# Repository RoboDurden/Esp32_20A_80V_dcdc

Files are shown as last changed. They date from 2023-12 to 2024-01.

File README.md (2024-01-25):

# Esp32_20A_80V_dcdc
 20A 80V dcdc/mppt with Esp32 and touch display

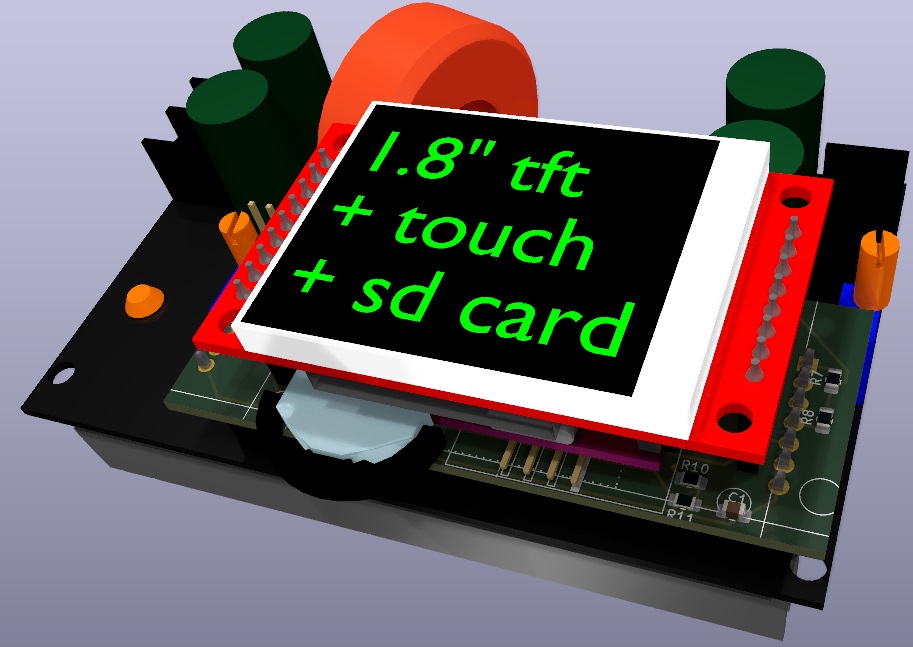
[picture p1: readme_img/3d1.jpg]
3d1


## KiCad pcb
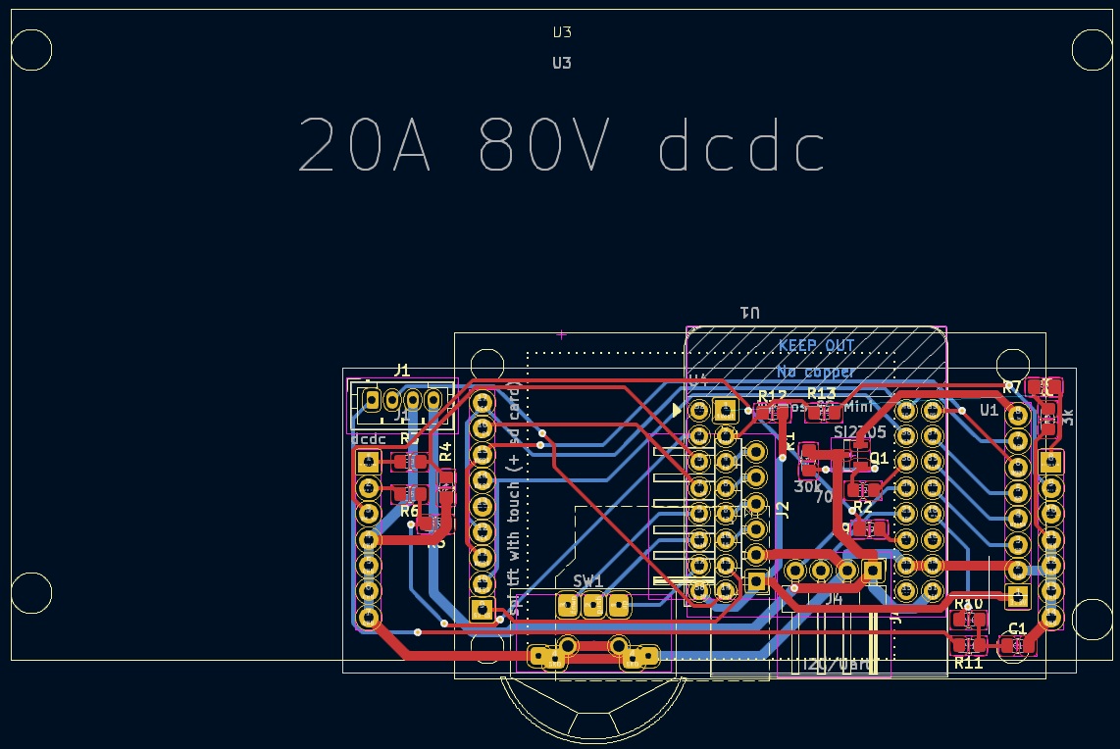
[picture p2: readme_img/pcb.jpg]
pcb


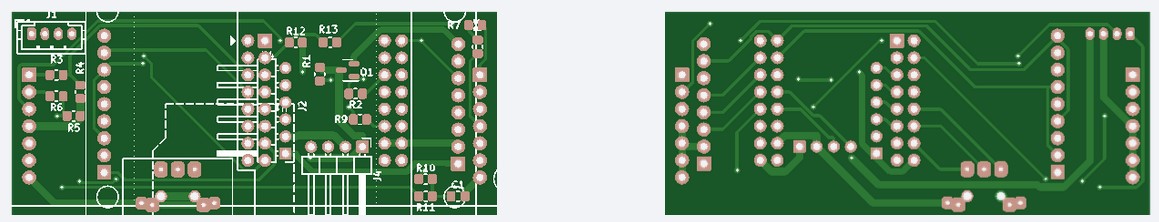
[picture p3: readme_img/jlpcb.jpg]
jlpcb


## replaces lcd pickup module
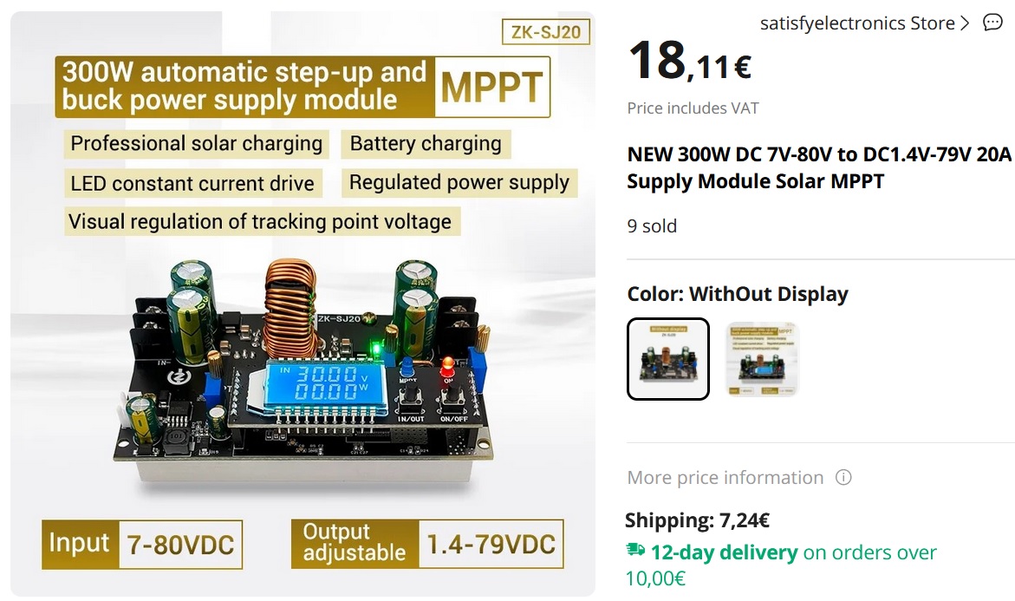
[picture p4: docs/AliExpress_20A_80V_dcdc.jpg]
AliExpress_20A_80V_dcdc

https://www.aliexpress.com/item/1005004966830126.html

## KiCad circuit
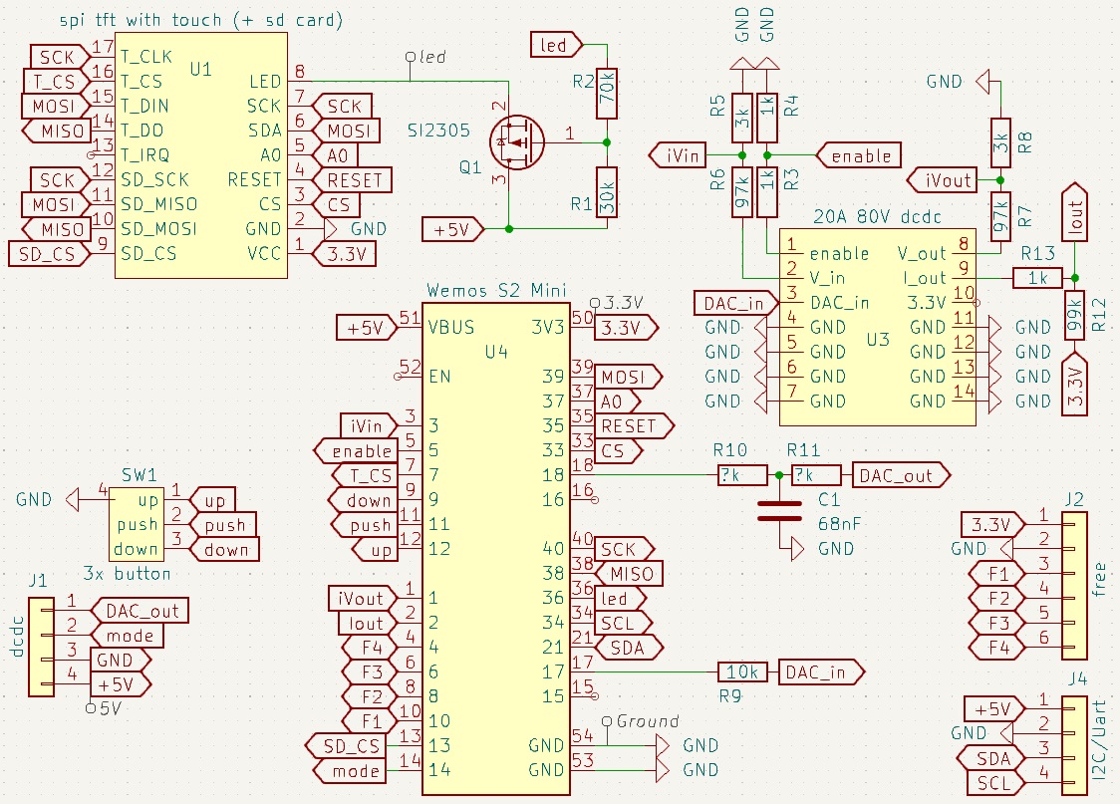
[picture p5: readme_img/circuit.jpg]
circuit


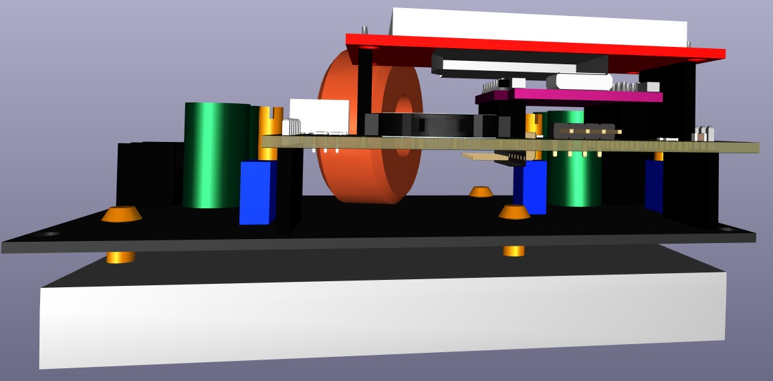
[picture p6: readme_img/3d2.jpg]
3d2

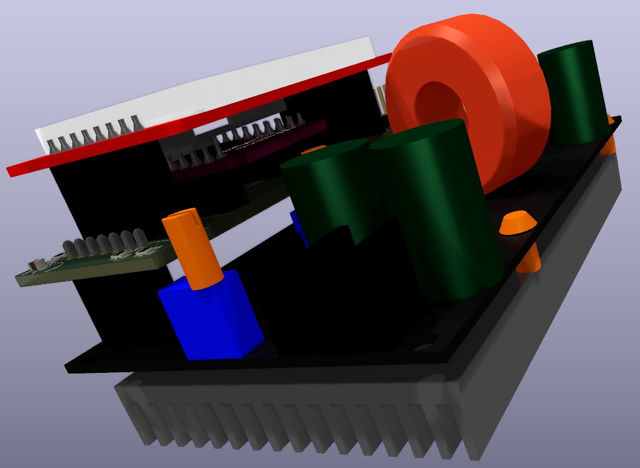
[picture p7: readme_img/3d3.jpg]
3d3


## blender 3d models
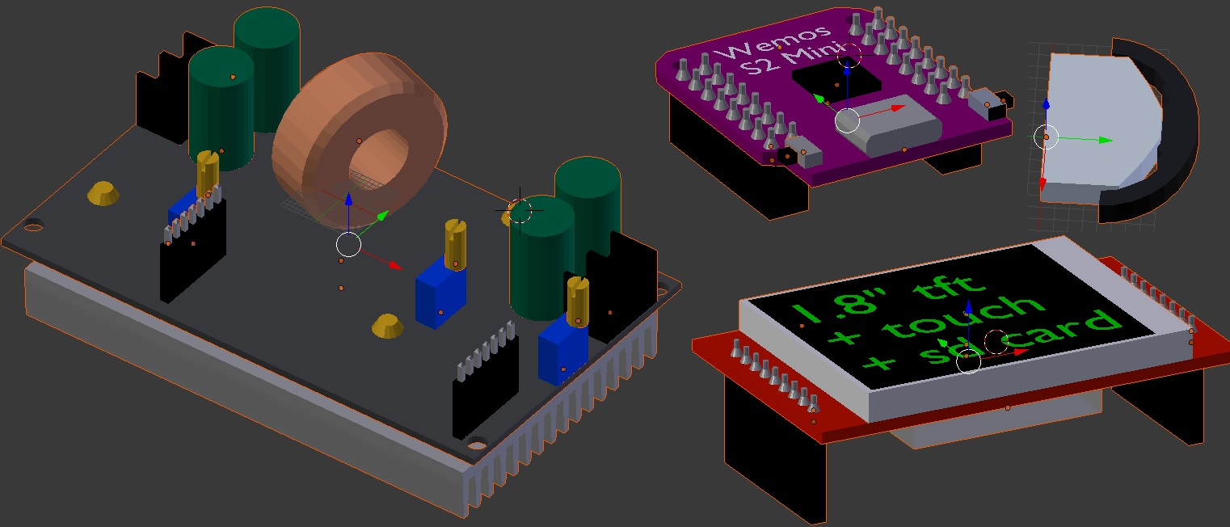
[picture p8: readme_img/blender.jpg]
blender


## blender box / housing
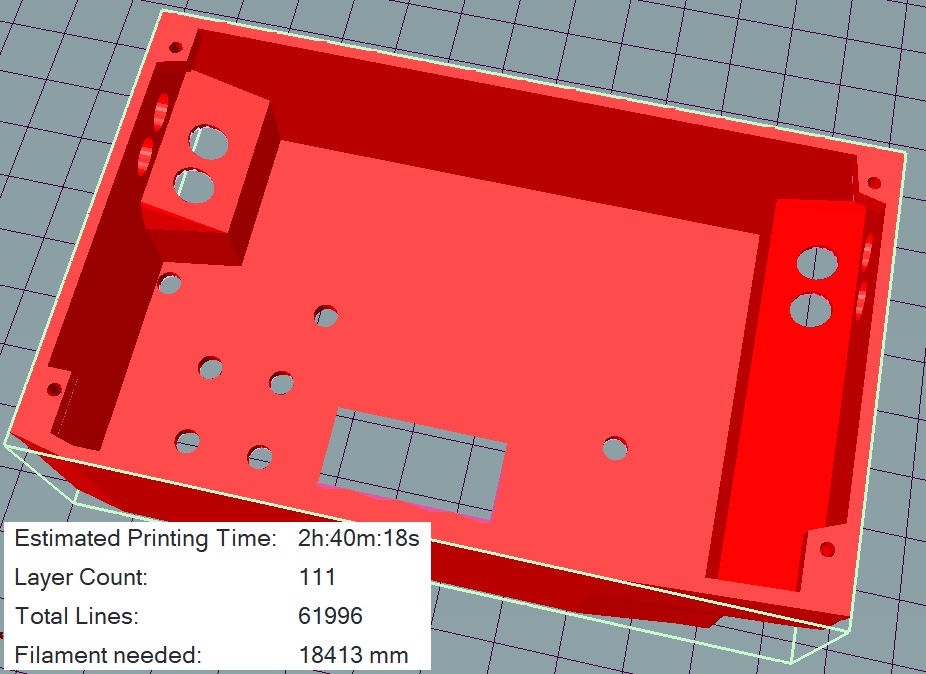
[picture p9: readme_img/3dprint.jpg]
3dprint


## Arduino code (ssd1306)
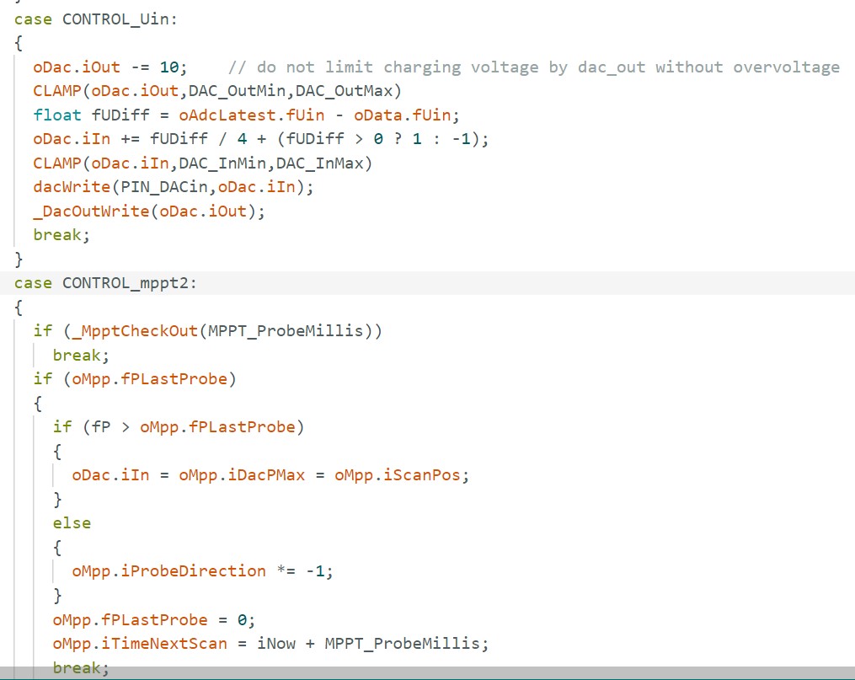
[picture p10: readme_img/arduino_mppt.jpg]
arduino_mppt


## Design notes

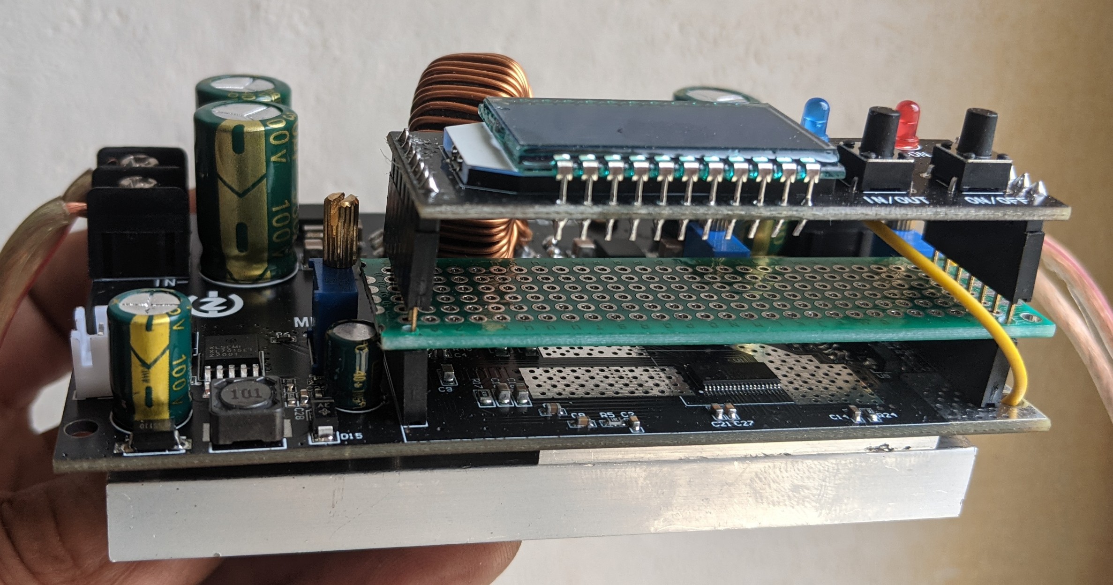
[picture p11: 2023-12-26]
docs/20A zwischenplatine.jpg

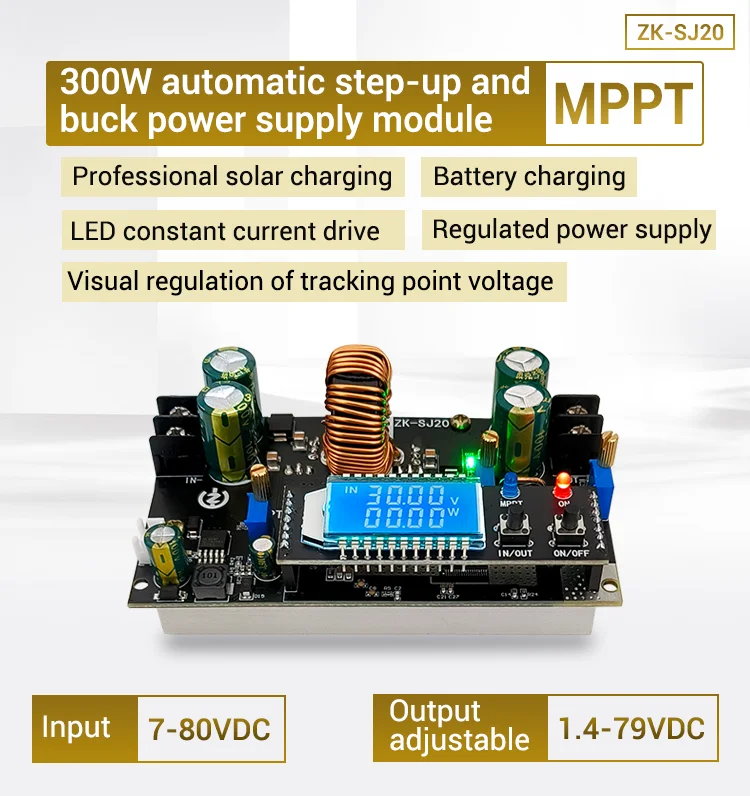
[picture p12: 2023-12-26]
docs/AliExpress dcdc/S2a203e523679416e9ab4497371176a7bX.webp

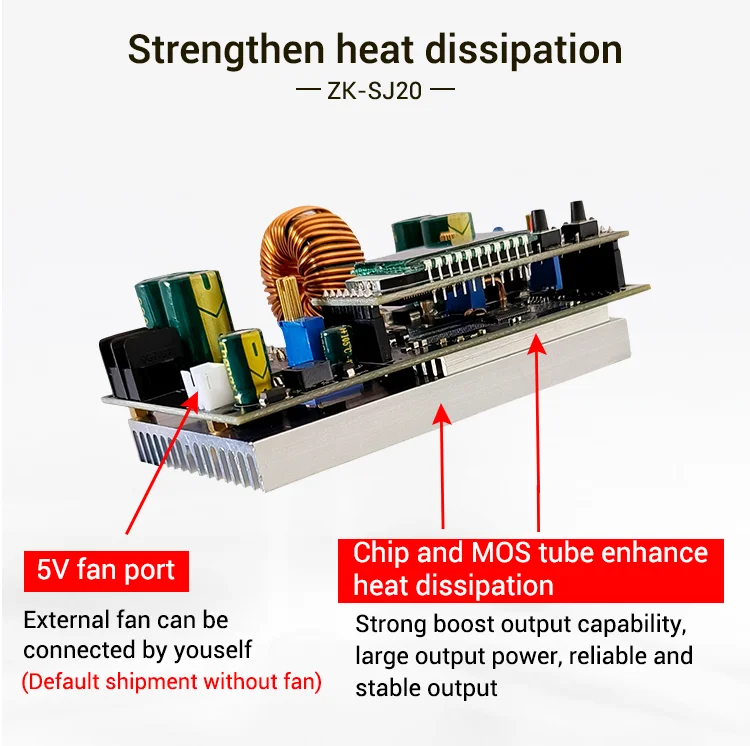
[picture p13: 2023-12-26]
docs/AliExpress dcdc/S84ae75041aaa493dba6d3abf79ab302bl.webp

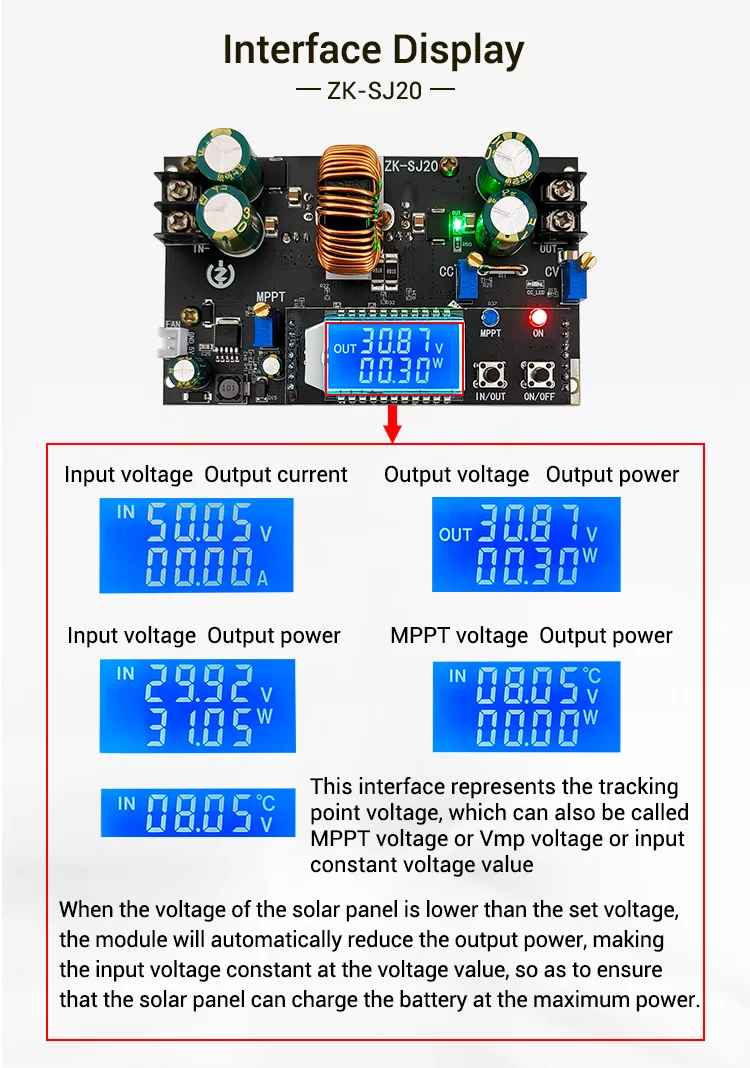
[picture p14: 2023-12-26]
docs/AliExpress dcdc/S4756472754be430b8e450a2648e028b7n.webp

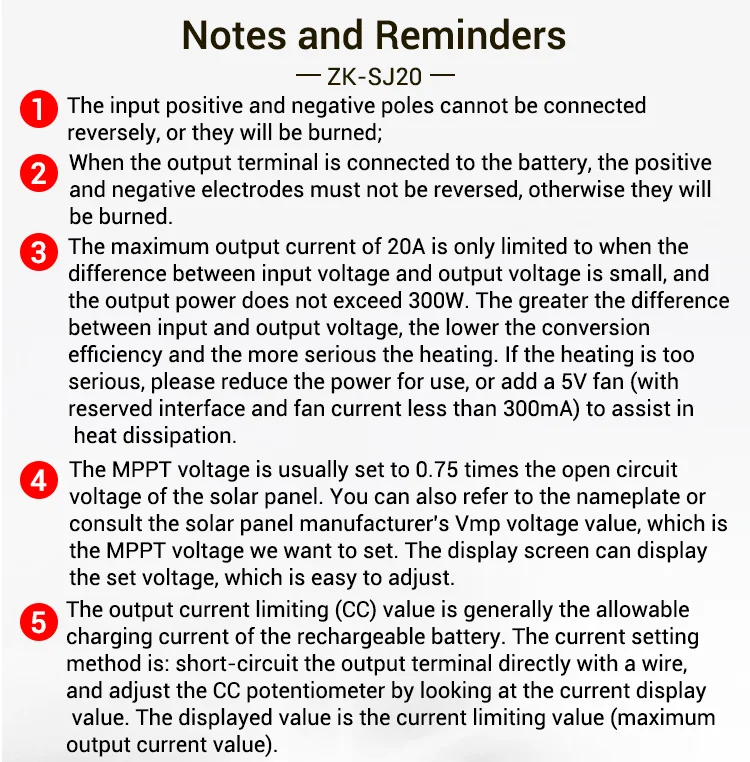
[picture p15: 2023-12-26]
docs/AliExpress dcdc/S0f6dcd9602464cfba2c723f9ad181f63F.webp

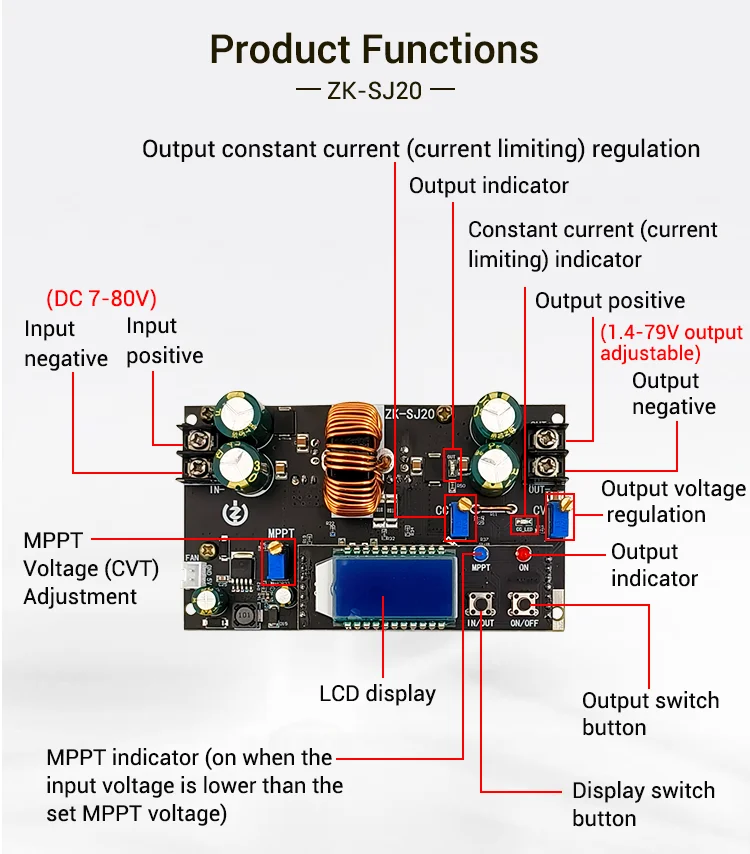
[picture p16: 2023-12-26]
docs/AliExpress dcdc/Sabfc8f4361d64af885e887af762c08adi.webp

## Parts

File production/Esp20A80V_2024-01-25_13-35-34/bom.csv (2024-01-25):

Designator | Footprint | Quantity | Value | LCSC Part #
C1 | 0805 | 1 | 68nF
J1 | JST_PH_B4B-PH-K_1x04_P2.00mm_Vertical | 1 | dcdc
J2 | PinHeader_1x06_P2.54mm_Horizontal | 1 | free
J4 | PinHeader_1x04_P2.54mm_Horizontal | 1 | I2C/Uart
Q1 | SOT-23 | 1 | SI2305
R1 | 0805 | 1 | 30k
R10, R11 | 0805 | 2 | ?k
R12 | 0805 | 1 | 99k
R13, R3, R4 | 0805 | 3 | 1k
R2 | 0805 | 1 | 70k
R5, R8 | 0805 | 2 | 3k
R6, R7 | 0805 | 2 | 97k
R9 | 0805 | 1 | 10k
SW1 | 3way dial switch | 1 | 3x button
U1 | display 128x160 +touch +sd | 1 | spi tft with touch (+ sd card)
U3 | 20A80V dcdc | 1 | 20A 80V dcdc
U4 | Wemos S2 Mini | 1 | Wemos S2 Mini

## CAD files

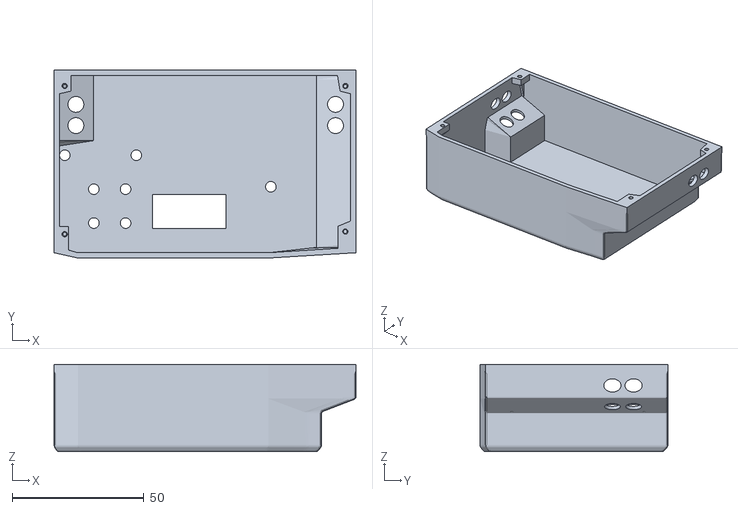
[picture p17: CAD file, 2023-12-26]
Blender housing/box 20A mppt no Esp32.stl
114.8 x 71.5 x 33.2

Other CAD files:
Blender housing/box 20A mppt 2.blend
Blender/Esp20A80V.blend

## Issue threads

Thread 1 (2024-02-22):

questions about the power supply module

AILIFE4798, 2024-02-22:
hi, i want to make a portable variable power supply controlled by esp32
i want to ask some question about the module
1. is the module synchronus aka there is 4 mosfet operating the inductor in full bridge
it can highly increase effiency and reduce heat
2. the original module have potentiometer for adjustment insted of button, that in most case mean it is not truely digitaly controlled, but i need my project to only use a single touch screen without any analog component, can the esp32 control the voltage and constant current
3. in these cheap module, the constant current is done in software, there is a pid loop to control the voltage based on the current feedback, so the software have to be very fast to react, i want to know if you set voltage to for example 30v and constant current 0.01a and connect a single led to it, will the supply react fast enough to not blow up the led

RoboDurden, 2024-02-23:
Long answer later.
Yes 4 mosfet.
My PCB is not tested yet.
My PCB only features 8 bit resolution for v_in and v_out. Potentiometers set the offset voltage, a resistor on PCB the range +- x Volt. So 2x/255 is the resolution.
Current control only via PID of voltage. Only good enough for charging or mppt .
Can not pull voltage down from 30V to 0.6V.
With external 4x 12bit DAC chip from MCP , direct digital current control should be possible.
There is a guy in Cina who designed a ltc8705 dcdc with four potentiometers. But I was not able to get in contact with him ...

RoboDurden, 2024-02-23:
http://m.eeworld.com.cn/RDesigns_detail/56242

AILIFE4798, 2024-02-23:
4 mosfet then this is the best module online ive seen so far
i have some 36v 4a ones with fp5139 pwm chip and same nuvoton microcontroller they are fully digital using encoder and button
i am willing to use external dac, but dac is not necessary in this case, using pwm and opamp is better(use pwm and rc filter, the opamp will have infinate input resistant and 0 output resistant to keep result stable)
esp32 have hardware pwm so it should be good
constant current via pid loop of voltage can be used as normal bench supply, dps5005 does that, and i know some other clones also do, just the software need to be fast and optimized
so with external dac can i control 0.6 to 50v at least 80v would be good to have
the guy that made his own module is not using digital control so its not really useful

AILIFE4798, 2024-02-23:
there is no such thing as digital pwm ic
they already are, just using a comparator as input voltage feedback and you have to offset it somehow
i will reverse engineer the 36v one that have 2 lm317 opamp
see how they designed it

idk what the input voltage adjust is used for
only out voltage this one is needed
i dont need hardware output current i will use voltage to control the current and always set hardware current to 10a for protection if esp software failed
why the module cannot regulate to 1v or so
i thought most modules can
you should use a opamp in series with rc filter, because the resistive divider will load the rc filter so higher frequency is required, opamp have true infinite input resistance so you can get much more resolution

RoboDurden, 2024-02-23:
Please post a cicruit with a opamp in series with rc filter to get nice dac from esp32 pwm.
V_in is needed for mppt.

AILIFE4798, 2024-02-24:
i have reverse engineered my 36v4a module
it actually have hardware current limiting with another set of opamp so maybe it really is needed

for each set of control, 2 opamp is used(one dual opamp package for one set of control), the output voltage/current feedback is first amplified by one opamp (the current shunt/voltage divider go to non inverting input, and a feedback resistor from output to inverting input) (just like how they do it for phase current, incase you havent recognized me now you do), the output of first opamp is connected to the microcontroller adc pin for feedback, and also connected to the second opamp non inverting input, the micro controller pwm pin is connected to a rc filter to the inverting input of the second opamp, and the second opamp output go to the pwm ic for buck boost

AILIFE4798, 2024-02-24:
i will send you pin tracing and schematic later

RoboDurden, 2024-02-24:
Please link the complete 36v4a module.
Even so I don't understand how this affects my 20A80V project here.

AILIFE4798, 2024-02-24:
you asked me how to control buck regulator ic with pwm and opamp
i say im not a professional either so lets do what the chines do the best just reverse engineer what others do and copy it
this is just what i have thats completely digitaly controlled
and have digital hardware current adjusment
this totaly can be fitted to the 80v20a one
you might need 4 set of opamps for it though but 4 pwm is easy on esp

AILIFE4798, 2024-02-24:
https://www.youtube.com/watch?v=hyLYPu-4EN8
this video explains it
if theres not enough space you can add another layer
the cost of pcb is same as 2 layer added is still smaller then 10x10
you just need to place the interconnect at different place of pcb
it would make it less mechanicaly stable but as long as touch screen is mounted correctly its ok

RoboDurden, 2024-02-24:
Okay, the opamp provides the current that effects the feedback input of the Lt8705. That gives more freedom for the low pass filter and a strong low pass can be achieved with a small capacity.
I need a strong current on the pwn output pin of about +-10 mA to keep the capacity small while still providing the current to change the dcdc feedback input.

But it works.
And multiple PCB layers are not the problem. There is no physical space left for a 8-sot on my compact pickup module.

And again, a tiny quad 12bit DAC controlled by i2c that does not need a PID loop to control current will also have stable output current to manipulate  dcdc feedback input.

And four times low pass plus quad opamp is way more complex.

Yes, if you only want to control output voltage, then adding an opamp is nice.

If I find physical space for an 8-sot opamp, I will consider your advice for a future version :-)

Thank you.

AILIFE4798, 2024-02-24:
i mean order a second piece of pcb and stack it once more so you have plenty more space to work with
and you can design it to be ordered as one piece but cut it to 2 at home so its cheaper

a dac would be good for replacing the rc filter, but can it output enough current to drive the feedback pin? i red in another video even with dac a output follower opamp is required, i think it depends on the dac chip

the 36v4a module is actually very clever
the code does not need to deal with the load and input voltage changing, as the micro controller only controls the comparator inverting input, the normal feedback is passed through the none inverting input, and this way the micro conntroller can still control the full voltage range 0-36v

i am going to make a similar thing and to avoid making a complete buck converter my self(which is possible with a esp32, but im not good at it), i want to try hack this 80v20a one as its the most powerful buck boost ive seen at this tiny size, switching supply especialy synchronus one really is superior
i got misleaded by some youtube video to use digital potentiometer as i do not know how opamp work before now i think about it its a very good idea ill buy some 80v20a module to try it out
the comercial module the ui is always very bad like this 36v4a module you will need to press the up and down button 36000 times to adjust the full range you can long press but its still very painful(btw, how did they get such amazing resolution PWM?or is it clever software)

RoboDurden, 2024-02-24:
Yes I will be happy if you also start working with this nice 20A80V module.
Another guy from the gen2.x repo did find the original manufacturer in China and he responded that he could offer a modified version for $15 at 100 pieces..
The two female headers have 8x gnd to give the LCD module stability.

It would be nice to have modified version that routes the additional lt8705 pins needed to the two female headers..

AILIFE4798, 2024-02-24:
and for these driver chip that have external mosfet, cant i just use more powerful mosfet and decrease current shunt resistance to increase the current rating
it shouldnt effect the chip function right

AILIFE4798, 2024-02-24:
i actually want to use ltc3780
the voltage is only 30v a bit low i want at least 50 but this module really is too big
i would still use it for a stationary bench supply that dont need to be portable but i want to make a portable version first

RoboDurden, 2024-02-24:
https://youtu.be/1vDQG1ODD4M
But yes, 30V limit :-(

AILIFE4798, 2024-03-05:
I have found another digital controlled DC DC module
It is using stm8 as controller
This time it is like your design the feedback connected to a pin with 2 layer rc filter directly
There is a opamp on board but it is used to amplify current only
This module can display voltage current but can only set voltage no constant current
(Interestingly the LCD is driven by the stm8 directly without driver ic, but I don't find any info online that stm8 have a built in LCD driver)

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

So yes every buck boost ic can be used for this digital control modification
What do you think is best that can output about 50v 5-10a,I need buck boost one cuz it'll be powered from 14v, and best if it is synchronous so less heat
Ltc3780 seems to be the best option despite the 30v problem
My current portable supply is 36v5a max 80w(long term 40w) which is in most case enough but as always we want more

RoboDurden, 2024-03-05:
14 v to 50 v is bad decision.
Step up is less efficient than step down.

AILIFE4798, 2024-03-05:
I am making a portable bench supply that will not often be used at 50v anyways it's just good to have for driving high voltage led
4s battery is maximum acceptable because 5v step up to charge it is very ineffecient also

RoboDurden, 2024-03-05:
If you want a range from 5V to 50V than this lt8705 module here is the best you can get for $20 in my opinion
Use a prototype board to test your opamp approach and report back :-)

AILIFE4798, 2024-03-05:
I want to make 1.5 to 50v
I mean I will need to charge the battery with USB
It's best to use USB pd that have 20v but it's not always available so it have to support 5v

The lt8705 is a good chip yes but the ready made module is too large I'll have to design a custom PCB and worry about the inductor and such
I don't need 20a
And the ltc3780 ready made module design is not the best certainly but well it's much more acceptable
I think the goal is to design a complete lt8705 based board but for now I'll start simple
I'll test with and without opamp
This really is my first time using opamp

RoboDurden, 2024-04-22:
Thank you for your interest @AILIFE4798 , major update online: https://youtu.be/tdmJfj5aSUM

I-hate-2FA, 2024-04-22:
I still haven't had time to mess with this yet
The mm32 project is good enough now I can finally take a rest and work on other thing and maybe finally make a video
I will surely give it a try though, I've recently seen a video making a digitally controlled electronic load with opamp and pwm, so I think I have now idea how to apply it to controlling buck boost converter also

RoboDurden, 2024-04-22:
Ah yes, the opamp to seperate the filtered output current from the pwm input current.
I am still confident that the max 40mA source- and 28mA sink-currents of the Esp32S2 are enough to control the feedback inputs of the LT8705
But please report on your findings with pwm + opamp :-)

I-hate-2FA, 2024-04-22:
I say I'm a hardware guy but I've never actually used a opamp on irl but I think I can learn how to use it easily if not too much math is involved

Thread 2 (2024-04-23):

10bit and 12bit dac with Esp32 ledcWrite()

RoboDurden, 2024-04-23:
I did some testing today to go from 8bit dac to 10bit or 12bit.
As the dac_2 does not work on my S2 Minis, i already had to use pwm and a 100 nF low pass anyway.
So i tested this PIN_DACout with higher bit ranges:

Here 10 bit with 10,000 Hz:
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

For 12 bit the frequency must be reduced to 5000 Hz, otherwise `ledcAttach(PIN_DACout, DAC_Freq, DAC_Bits)` will fail:
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

14 bit only succeeds at 2000 Hz but i guess that would need a 1 uF low pass:
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

@AILIFE4798, you need an opamp when you want to drive something like a loudspeaker.
I am still confident that the max 40mA source- and 28mA sink-currents of the Esp32S2 are enough to control the feedback inputs(!) of the LT8705

Here the Arduino test code. 'f5000' sent from the terminal will change frequency to 5000 Hz, 'b8' will set the bit range to 8:
```

#define ESP32_CORE3  // new 3.0.x Espressif Arduino Core needs differet ledc functions :-/

#define SERIALDEBUG Serial  // uncomment to disable Serial 115200 baud debug output
#ifdef SERIALDEBUG
  #define OUT2T(s,i)  {SERIALDEBUG.print(s);SERIALDEBUG.print(": ");SERIALDEBUG.print(i);SERIALDEBUG.print("  ");}
  #define OUT2N(s,i)  {SERIALDEBUG.print(s);SERIALDEBUG.print(": ");SERIALDEBUG.print(i);SERIALDEBUG.println();}
#else
  #define OUT2T(s,i)
  #define OUT2N(s,i)
#endif

#define PIN_DACin   17
#define PIN_DACout 18
#define LED_BUILTIN 16

#define DAC_Freq 5000
#define DAC_Bits 12

uint8_t iBits = DAC_Bits;
uint32_t iFreq = DAC_Freq,iFreqSet;

#define CHANNEL_DacOut 0  // Arduio ESP32 Core 2.x needs channel

void DacChange()
{
  #ifdef ESP32_CORE3
    iFreqSet = ledcChangeFrequency(PIN_DACout, iFreq, iBits);
  #else
    iFreqSet = ledcSetup(CHANNEL_DacOut, iFreq, iBits);  // configure LED PWM functionalitites
    ledcAttachPin(PIN_DACout, CHANNEL_DacOut);  // attach the channel to the GPIO to be controlled
  #endif
}

void DacSetup()
{
  #ifdef ESP32_CORE3
    iFreqSet = ledcAttach(PIN_DACout, iFreq, iBits);
  #else
    iFreqSet = ledcSetup(CHANNEL_DacOut, iFreq, iBits);  // configure LED PWM functionalitites
    ledcAttachPin(PIN_DACout, CHANNEL_DacOut);  // attach the channel to the GPIO to be controlled
  #endif
}

void DacWrite(uint32_t iOut)
{
  #ifdef ESP32_CORE3
    ledcWrite(PIN_DACout, iOut);
  #else
    ledcWrite(CHANNEL_DacOut, iOut );
  #endif
}

void setup()
{
  Serial.begin(115200);

  // Initialize pins as LEDC channels
  // resolution 1-16 bits, freq limits depend on resolution, channel is automatically selected
  //ledcAttach(PIN_DACout, 10000, 8); // 10 kHz PWM, 8-bit resolution

  pinMode(LED_BUILTIN,OUTPUT);

  DacSetup();

}

#define TIME_Display 500
unsigned long iNow,iTimeDisplay=0;
void loop()
{
  //OUT2T("iFreq",iFreq)
  iNow = millis();
  digitalWrite(LED_BUILTIN,iNow%1000<500 ? 1 : 0);

  if (Serial.available())
  {
    String s = Serial.readStringUntil('\n');
    OUT2T("serial input",s)
    char c = s.charAt(0);
    s = s.substring(1);
    switch(c)
    {
      case 'f':  iFreq = s.toInt();   OUT2T("set new frequency",iFreq)  break;
      case 'b':  iBits = s.toInt();  OUT2T("set new bit resolution",iBits)  break;
    }
    DacChange();
  }

  uint32_t iRange = (2 << (iBits-1));
  uint32_t iOut = (micros()/100) % iRange;

  DacWrite(iOut);

  if (iNow < iTimeDisplay)
    return ;
  iTimeDisplay = iNow + TIME_Display;

  OUT2T("Hz 'f'", iFreqSet)  OUT2T("bits 'b'",iBits)  OUT2N("range",iRange)
}
```

RoboDurden, 2024-04-23:
If 30 mA would be the max current of the dac pin, then the low pass resistor should not be smaller than 3V/0,03A = 100 Ohm.
I am using R10=12k + R11=0.9k = 12.9k and can control the output voltage from 27.6V to 58.8V.
That is a range of 31.2 Volt, divided by 255 steps gives a resolution of 0.12 Volt, that currently needs to be shifted with the original potentiometer on the dcdc module if you would want to charge a 12 Volt battery..

I can easily go to 10 bit and would have a step size of 0.03 Volt.

And reducing R10 to 3.3k might already give the full range from 1.4V to 79V.

RoboDurden, 2024-04-24:
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

I-hate-2FA, 2024-04-24:
for refrence,this is a schematic of a dps5005 power supply
https://github.com/kanflo/opendps/blob/master/hardware/reverse-engineering/dps3003/DPS3003.pdf

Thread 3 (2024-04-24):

v2 = soldering ESP32 directly to the backside

RoboDurden, 2024-04-24:
PCB and S2_Mini are cheap, so simply solder S2_Mini to backside. The tin solder should quickly be sucked into the holes of the S2_Mini and connect to the holes of the pcb :-)

And with a heat gun, the Wemos S2 Mini should quickly drop off ?

I have reduced the footprint pad sizes of the S2Mini to 1.5 mm (like the original) to allow a track to pass in between:

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

RoboDurden, 2024-04-24:
There is exactly just enough space underneath for the S2Mini to go above the cc potentiometer:

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

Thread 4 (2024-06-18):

ZK-SJ30 30A dcdc model with better efficiency ?

RoboDurden, 2024-06-18:
There is a 30A version with the same LCD module, so it might be compatible with this project.

22,59€  39%OFF | ZK-SJ30 700W High Power Auto Boost Power Module Synchronous Rectifier 30A Solar Charging MPPT
https://a.aliexpress.com/_EHqaZRz

I am not satisfied with the efficiency of the 20A dcdc. At best I verified an efficiency of only 92%. A really boring video with lots of input output measurements that I do not think with uploading to YouTube..

@I-hate-2FA , what would this 30A dcdc module would cost on these platforms ?

https://my.world.taobao.com/item/789873368119.htm

Use $10 ? But what about shipping ??

https://www.ruten.com.tw/item/show?22420585284046

??

I will order two modules on AliExpress and test the efficiency. Hopefully they have better mosfets..

The one customer feedback sounds promising:

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

(I will finalize v3 in the next two weeks..)

I-hate-2FA, 2024-06-19:
is this one also buck-boost topology or other
because the inductor is tiny for its power, i dont believe the specs at all
and what main chip is it using

the module cost $25usd with display or $20 without, idk abt the shipping, it is viewed with china version of the website

RoboDurden, 2024-07-01:
@I-hate-2FA you will find more happiness if you think positive..

This 30A version has 8 mosfet instead of the normal 4 mosfet of the 20A version.
So half the resistance. That should indeed alow for more currents or better efficiency.

30A: https://wmsc.lcsc.com/wmsc/upload/file/pdf/v2/lcsc/2202132000_KIA-Semicon-Tech-KCB3008B_C2839423.pdf
RDS(on).typ= 4.5 mΩ , 85 V
20A: https://www.huanqiuic.com/uploads/pdf/20220108/pYYBAGG25B2APGWxAAWzSyBL_80872.pdf
RDS(on).typ= 4.3mΩ , 82 V

The 30A version has 12V regulator onboard available to the 2-pin fan socket, the 20A module has 5V.
Which i use to power the ESP32 and tft display.
So my pickup module will need an an additional 5V regulator.

The two female headers seem to be compatible to my module.
Yes there is 3.3V on the third pin of the right header. Which normally powers the lcd module.
So it might be possible to use this to power my esp32 and tft (which will be not as bright as 5V but still good to see.).
But that would need a v4 of this pcb here.
And this 3.3V seem to come from a linear regulator. So from 11.40 (12V) down to 3.3V :-( Okay for the low power consumption of the original lcd module, but not really nice for wifi-esp32 + tft + i2c modules..

v3 will be delieverd in a few days. But i will assemble it in about 2-3 weeks i guess.

RoboDurden, 2024-07-02:
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

I added the nice 14A ltc3780 setup step down module for which I have verified 97% efficiency.
So I do not think that the coil of the lt8705 modules are undersized.
They both have four wires in parallel.

I-hate-2FA, 2024-07-02:
the module just look small on the listing, it is actually huge, way too large for my project
my portable psu recently broke down, is is very unstable, already burned 2 motherboard because the output went out of control, i really need to start building a new one

RoboDurden, 2024-07-02:
I am satisfied with this stepdown module: https://youtu.be/fOnTM6UMRIU

I-hate-2FA, 2024-07-02:
> I am satisfied with this stepdown module: https://youtu.be/fOnTM6UMRIU

the problem is i need buck boost one(work on 2~6s lipo voltage), and controlled by esp32

I-hate-2FA, 2024-07-02:
the one you have can be controlled by esp with serial, but it will only output less then 12v which is not enough, ideally i want 50v, but 36v is also ok

I-hate-2FA, 2024-07-02:
i also ideally want it to fit in standard powerbank size, it is clearly possible with current tech but not with readlly available module

RoboDurden, 2024-07-02:
the module can go below 12V! Have quickly made a video for you: https://youtu.be/4G_sZVq6stk
But as it has a range of 1.2V - 80V, the potentiometer is very sensitive. But later in the video i demonstrate that it is also very sensitive for 30V, and for such voltages my v2 board with 10 bit software/filter dac works nicely.

I-hate-2FA, 2024-07-02:
> the module can go below 12V! Have quickly made a video for you: https://youtu.be/4G_sZVq6stk But as it has a range of 1.2V - 80V, the potentiometer is very sensitive. But later in the video i demonstrate that it is also very sensitive for 30V, and for such voltages my v2 board with 10 bit software/filter dac works nicely.

looks great, good for desktop power supply, but too large for portable one, and still need to figure out how to control feedback pin with micro controller, and not sure if the constant current is fast enough for a bench supply as its only meant for charge battery (if you set to 12v and connect 5mm led it wont explode then its good)

and i want to know, does the potentiometer have full 80v on it? because it will be operating out of specs, but its chinese product i wont be surprised if it is, if so it rules out any possibility of digital potentiometer

im curious how does comercial digitally controlled module have such good accuraicy, with max 50v and 0.001v resolution, what is the pwm frequency they used?

RoboDurden, 2024-07-02:
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

I-hate-2FA, 2024-07-02:
> This sounds rather like a Kickstarter project then only for your personal use :-)

it is just for my personal use, but if it happens i will make a video (a showcase at lease) with all the design files if you want to build one, nowadays custom pcb and 3d printing just make it possible to be done at home, heck you can even order custom silicon now

RoboDurden, 2024-07-02:
Well for personal use you mostly do not need a super small and compact design !
Only when you want to compete with other products and stand out as "the smallest portable power supply", would you need something not yet seen.
So if you do not see a success of a 100 pcs Kickstarter, it is probably not worth doing it.

Very strangely i tested the full range of the 30A for you and with this high sensitivity the output went to 96V with only 2 or three turns of the potentiometer.
Then something happened and the module changed to the nice slow sensitivity with 25 turns to achieve a range from 1.x Volt up to only 72 Volt.
And then it also had good control at the very low voltage regime.
With my 10 bit dac i think at least achive 0.1 Volt control easily.

If you want to go above 30 Volt, i think there currently is only see the LT8705 on the market.

I-hate-2FA, 2024-07-02:
> Well for personal use you mostly do not need a super small and compact design !
> Only when you want to compete with other products and stand out as "the smallest portable power supply", would you need something not yet seen.

because i actually will need to bring it with me everywhere so i want to make it reasonably compact
there is already comercial mini power supply powered from usb pc with 100w 30v 5a
https://www.youtube.com/watch?v=Pd6LG7iP2GQ
but i need more feature then that, so ill make my own

> Very strangely i tested the full range of the 30A for you and with this high sensitivity the output went to 96V with only 2 or three turns of the potentiometer.
> Then something happened and the module changed to the nice slow sensitivity with 25 turns to achieve a range from 1.x Volt up to only 72 Volt.

bad connection inside the potentiometer

> With my 10 bit dac i think at least achive 0.1 Volt control easily.
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
RoboDurden, 2024-07-02:
> Input 10.5-70V  , Output 5-58V

That looks very much like step down only.

I-hate-2FA, 2024-07-02:
the reason allot of module have max 36v is if you need more a seperate small buck converter is needed to power the pwm chip, like the 180w one have

> That looks very much like step down only.

chinese description says it can increase,decrease voltage, and same input voltage as output, yes it can only output 58v but the input can be at 12v

I-hate-2FA, 2024-07-02:
> But it is cheap - please test it :-)

ok, buy it locally is only 3x the price compared to buy from china, it is still acceptable

the seller linked a test video, i was gonna send it to you but it is for completely different module

I-hate-2FA, 2024-07-02:
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
i have reverse engineered the schematic of the 180w one, it match a sepic converter, which can buck boost
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

RoboDurden, 2024-07-02:
I will not sponsor such a dcdc module, you have to buy it yourself.
This is not really about making the world a better place.
But nice reverse engenieering !
Maybe i will order one as well to test efficiency. But it is rated for 30 Watt only without the heat sink. So It might perform poorly anyway..

I-hate-2FA, 2024-07-02:
> I will not sponsor such a dcdc module, you have to buy it yourself.

it is ok, i already said i will

> Maybe i will order one as well to test efficiency. But it is rated for 30 Watt only without the heat sink. So It might perform poorly anyway.

it is not synchronus, effiency always worse

I-hate-2FA, 2024-07-02:
if you want high effiency, small size, high power, this is the best one you can buy
https://de.aliexpress.com/item/1005007259645809.html
based on lt8390 or isl81601, but it is too expensive

RoboDurden, 2024-07-02:
Yes to expensive for me.
Bye for now, i want to focus on my new diy boiler heater i make out of 16x 60cm carbon/silikon heat wires: https://de.aliexpress.com/item/1005005192378143.html

I-hate-2FA, 2024-07-02:
i am working on replace appliance motherboard with esp32 running esphome

I-hate-2FA, 2024-07-15:
i have ordered both the 180w sepic converter and the 1000w full bridge buck boost converter thats way overpriced
lets see when they will arrive

RoboDurden, 2024-07-15:
I don't think that these will be useful for my project here.

I-hate-2FA, 2024-07-15:
but now i think about it, there is a much better solution
we could just use a buck boost converter chip that is intended to be controlled by a micro controller
like for example this one
https://cn.southchip.com/upload/file/SC8806_datasheet_brief_en.pdf
it is full bridge synchrnous, with external nmos so you can increase the current capability as much as you like, and directly use i2c to control the output voltage and current by hardware, with included protection feature
even better is this chip support invert input and output, so you can use it to charge a battery

RoboDurden, 2024-07-15:
i do not feel experienced enough to design a dcdc module from scratch. And this chip can only handle up to 30V :-(
Nor is it available on LCDC or mouser.

You remind me of myself when i was 20 years younger. A dreamer who always wants to create the perfect thing.
I strongly recomend that you watch Fight Club - at least ten times.

perfection is for failures.

roland
"you either lose.. or fail - nothing else, nothing in between."

I-hate-2FA, 2024-07-15:
> i do not feel experienced enough to design a dcdc module from scratch.

just order one from jlcpcb
https://oshwhub.com/Monnina/SC8721QFERfang-an-yan-zheng-ban
and ofc you can download the pcb file and edit it if needed

> And this chip can only handle up to 30V :-(

these chip is designed for usb pd so unfortunately yes it will have the 36v hard limit, we are going to misuse it for bench supply and battery charger

> Nor is it available on lcdc or mouser.

yeah not available on lcsc yet, mouser is just trash it dont even have the ch32v003 yet, it will never have good things

I-hate-2FA, 2024-07-15:
with usb pd 4.0 which need 48v, we are expecting 60v chips to come in about 2-4 years

I-hate-2FA, 2024-07-15:
https://oshwhub.com/killy.thi/SC8815-200W-Bidirectional-BuckBoost
the one i sent the chip have internal switch, this one have external one(also i2c controlled)

RoboDurden, 2024-07-15:
Sure, when such a module is available on AliExpress for $20- i might like to make such a pickup module for this like i am trying to do here for ZK-SJ20 module. But still there is the 30V limit, which makes it pretty much useless for solar charging or hoverboards

I-hate-2FA, 2024-07-30:
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

I-hate-2FA, 2024-07-30:
180w one can buck boost I tested

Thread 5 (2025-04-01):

XY-SK120x buck boost mode variable supply with serial control

I-hate-2FA, 2025-04-01:
I have got a XY-SK120 module which is the first buck boost module that offers a serial interface, do you have any documentation about how to use out with a esp insured of their accessories, apparently it have a bootloader so you can flash it with serial too

I-hate-2FA, 2025-04-01:
The MCU is hk32 64kb, without a graphical display it is plenty

RoboDurden, 2025-04-01:
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

As they also offer a rs485 module, I think there must be a serial protocol available.

The wifi module is a esp8285. Maybe it only works in conjunction with their proprietary app ? No connection to users home wifi but only with it's own hotspot like cheap dashcams ?
Then you should still be able to hack the protocol by sniffing the Rx and Rx lines

RoboDurden, 2025-04-01:
I would prefer the 900W step down only as it can handle 70V

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

good ot for 48V systems.

But after it broke (rainy day), I replaced it with a cheap analog 80V 20A step down:

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

Your use case is USB PD if you're remember correctly, so you need step up as well.

I-hate-2FA, 2025-04-01:
i want to connect the supply serial and some other things to esp, and connect esp to a modified phone with otg, and from the app i control the esp that translate to the power supply

I-hate-2FA, 2025-04-01:
i have used mqtt before, it is not hard yeah, the server can be hosted on the phone directly and using reverse proxy over the internet if you want, but it is not what i want, i want to integrate the phone into the project permanantly, since a phone with much more processing power then any of the HMI touch screen is cheaper for me to get and making a app is super easy, so usb is more reliable in thias case, why would you want internet if they are always in the same enclosure

i will try if the 70v step down protocol works

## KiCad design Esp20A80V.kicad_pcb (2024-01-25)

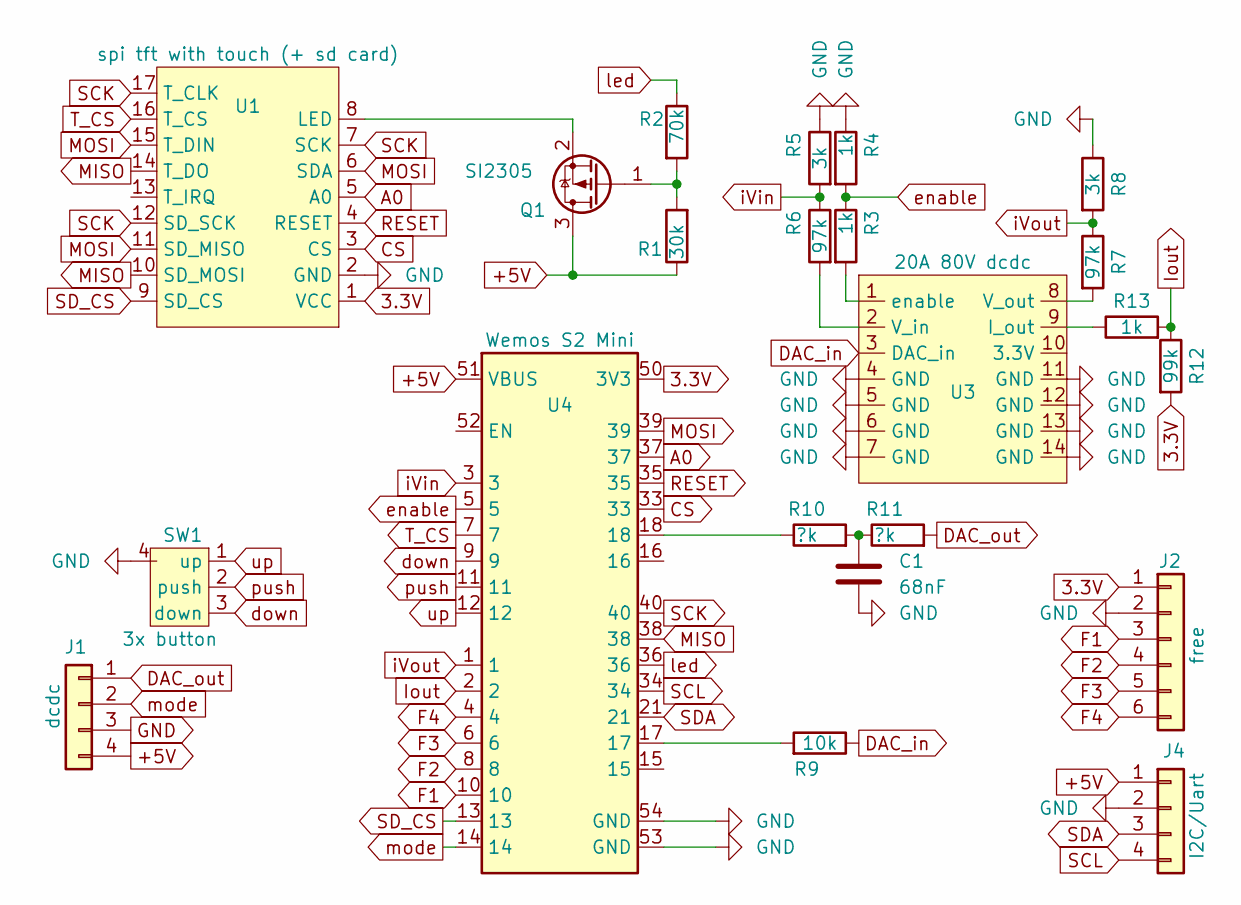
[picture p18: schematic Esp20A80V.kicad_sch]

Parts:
C1: 68nF; C_0805_2012Metric_Pad1.18x1.45mm_HandSolder
J1: dcdc; JST_PH_B4B-PH-K_1x04_P2.00mm_Vertical
J2: free; PinHeader_1x06_P2.54mm_Horizontal
J4: I2C/Uart; PinHeader_1x04_P2.54mm_Horizontal
Q1: SI2305; SOT-23
R1: 30k; R_0805_2012Metric_Pad1.20x1.40mm_HandSolder
R2: 70k; R_0805_2012Metric_Pad1.20x1.40mm_HandSolder
R3, R4, R13: 1k; R_0805_2012Metric_Pad1.20x1.40mm_HandSolder
R5, R8: 3k; R_0805_2012Metric_Pad1.20x1.40mm_HandSolder
R6, R7: 97k; R_0805_2012Metric_Pad1.20x1.40mm_HandSolder
R9: 10k; R_0805_2012Metric_Pad1.20x1.40mm_HandSolder
R10, R11: ?k; R_0805_2012Metric_Pad1.20x1.40mm_HandSolder
R12: 99k; R_0805_2012Metric_Pad1.20x1.40mm_HandSolder
SW1: 3x button; 3way dial switch
U1: spi tft with touch (+ sd card); display 128x160 +touch +sd
U3: 20A 80V dcdc; 20A80V dcdc
U4: Wemos S2 Mini

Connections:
3.3V: J2.1, R12.2, U1.1 (VCC), U4.50 (3V3)
+5V: J1.4, J4.1, Q1.3 (D), R1.1, U4.51 (VBUS)
A0: U1.5 (A0), U4.37
CS: U1.3 (CS), U4.33
DAC_in: R9.1, U3.3 (DAC_in)
DAC_out: J1.1, R11.2
F1: J2.3, U4.10
F2: J2.4, U4.8
F3: J2.5, U4.6
F4: J2.6, U4.4
GND: C1.2, J1.3, J2.2, J4.2, R4.1, R5.1, R8.1, SW1.4, U1.2 (GND), U3.4 (GND), U3.5 (GND), U3.6 (GND), U3.7 (GND), U3.11 (GND), U3.12 (GND), U3.13 (GND), U3.14 (GND), U4.53 (GND), U4.54 (GND)
Iout: R12.1, R13.2, U4.2
MISO: U1.10 (SD_MOSI), U1.14 (T_DO), U4.38
MOSI: U1.6 (SDA), U1.11 (SD_MISO), U1.15 (T_DIN), U4.39
unnamed: C1.1, R10.2, R11.1
unnamed: Q1.1 (G), R1.2, R2.2
unnamed: Q1.2 (S), U1.8 (LED)
unnamed: R9.2, U4.17
unnamed: R10.1, U4.18
unnamed: R13.1, U3.9 (I_out)
unnamed: R6.2, U3.2 (V_in)
unnamed: R7.2, U3.8 (V_out)
unnamed: R3.2, U3.1 (enable)
RESET: U1.4 (RESET), U4.35
SCK: U1.7 (SCK), U1.12 (SD_SCK), U1.17 (T_CLK), U4.40
SCL: J4.4, U4.34
SDA: J4.3, U4.21
SD_CS: U1.9 (SD_CS), U4.13
T_CS: U1.16 (T_CS), U4.7
down: SW1.3 (down), U4.9
enable: R3.1, R4.2, U4.5
iVin: R5.2, R6.1, U4.3
iVout: R7.1, R8.2, U4.1
led: R2.1, U4.36
mode: J1.2, U4.14
push: SW1.2 (push), U4.11
up: SW1.1 (up), U4.12

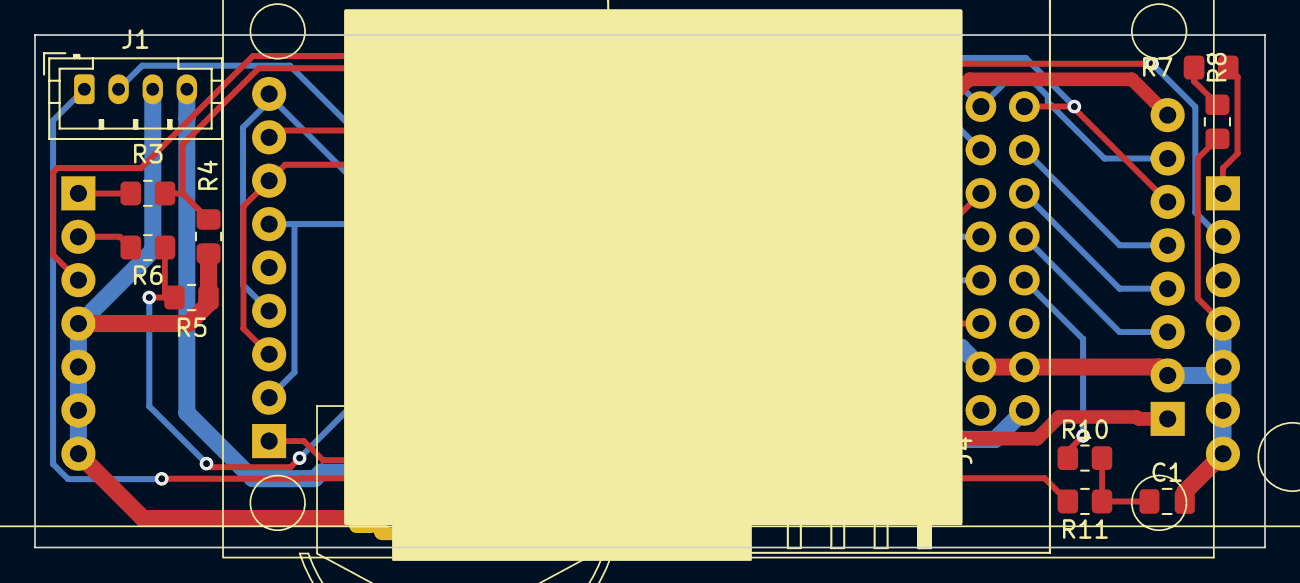
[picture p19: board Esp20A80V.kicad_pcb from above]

Board: 2 copper layers, 72.0 x 30.0 mm, 22 parts (0 on the bottom side), 37 nets.

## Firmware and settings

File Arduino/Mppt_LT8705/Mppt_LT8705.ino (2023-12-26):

  // mppt with the 20A 80V LT8705 step-up-down module and an ESP32 S2 Mini :-)
#define SERIALDEBUG Serial  // uncomment to disable Serial 115200 baud debug output

#include "include.h"

void setup() 
{
  pinMode(PIN_Uin,INPUT);
  esp_sleep_wakeup_cause_t wakeup_reason = esp_sleep_get_wakeup_cause();
  if (wakeup_reason == ESP_SLEEP_WAKEUP_TIMER)
  {
    float fUin    = mapf(analogRead(PIN_Uin),   0.0, 5957.0 ,  0.0, 40.00 ,false);
    if (fUin < 5.0)
    {
      esp_sleep_enable_timer_wakeup(5 * uS_TO_S_FACTOR);
      OUT2N("Going to sleep now, U_in",oAdcLatest.fUin)
      esp_deep_sleep_start();
    }
  }

  
  #ifdef SERIALDEBUG
    SERIALDEBUG.begin(115200);
  #endif
  OUTN("mppt with the 20A 80V LT8705 step-up-down module and an ESP32 S2 Mini :-)");

  pinMode(LED_BUILTIN, OUTPUT);

  pinMode(PIN_Uout,INPUT);
  pinMode(PIN_Iout,INPUT);

  //pinMode(PIN_DACin,INPUT);   // to not set an output hi or low level but analogOut
  
  dacDisable(PIN_DACin);
  //dacDisable(PIN_DACout); 

  _DacOutDisable(); // pinMode(PIN_DACout,INPUT);
  ledcSetup(CHANNEL_DacOut, 10000, 8);  // configure LED PWM functionalitites
  ledcAttachPin(PIN_DACout, CHANNEL_DacOut);  // attach the channel to the GPIO to be controlled


  pinMode(pin_Left, INPUT_PULLUP);
  pinMode(pin_Right, INPUT_PULLUP);
  pinMode(pin_Push, INPUT_PULLUP);

 
  // initialize digital pin LED_BUILTIN as an output.
  pinMode(LED_BUILTIN, OUTPUT);

  EEPROM.begin(512);
// load EEPROM data into RAM, see it
  EEPROM.get(0,oData);
  OUT2T("EEPROM version",oData.iVersion)  OUT2N("sSSID",oData.sSSID) 
  if (oData.iVersion != EEPROM_VERSION)
  {
    Data oNew;
    oData = oNew;
    EEPROM.put(0,oData);
    EEPROM.commit(); 
  }

  oAdcLogMax.fUin = 1.1 * oData.fUin;
  oAdcLogMax.fUout = 1.1 * oData.fUout;
  oAdcLogMax.fIout = 1;

  display.init();
  display.flipScreenVertically();

  display.clear();
  display.setTextAlignment(TEXT_ALIGN_LEFT);
  display.setFont(ArialMT_Plain_16);
  display.drawString(0, 0, "Hello world");
  display.setFont(Dialog_plain_32); // ArialMT_Plain_10
  display.setTextAlignment(TEXT_ALIGN_CENTER);
  display.drawString(60, 32,"Robo :-)" );
  display.display();

}

void PrintFloat(int x, int y, float f, int iDecimals=1, String sUnit="", int iMinWidth=3)
{
  char s[6];     //result string 5 positions + \0 at the end
  dtostrf(f, iMinWidth, iDecimals, s );
  if (sUnit == "")
    display.drawString(x, y,s );
  else
  {
    sUnit = String(s)+sUnit;
    display.drawString(x, y,sUnit );
  }
}


void ReadInput()
{
  wButtons = 0;
  if (Serial.available())
  {
    String s = Serial.readStringUntil('\n');
    OUT2T("serial input",s)
    char c = s.charAt(0);
    s = s.substring(1);
    //char c = Serial.read();
    switch(c)
    {
    case 'a': wButtons = _ButtonDown; break;
    case 's': wButtons = _ButtonPush; break;
    case 'd': wButtons = _ButtonUp; break;
    case 'i': if (s.length()){oData.fUin = s.toFloat();} OUT2N("oData.fUin",oData.fUin) SettingSave(); return;
    case 'o': if (s.length()){oData.fUout = s.toFloat();} OUT2N("oData.fUout",oData.fUout) SettingSave(); return;
    case 'm': if (s.length())
      {
        c = s.charAt(0);
        switch(c)
        {
        case '0': ControlInit(CONTROL_NONE); break;
        case 'o': ControlInit(CONTROL_Uout); break;
        case 'i': ControlInit(CONTROL_Uin); break;
        case 'm': ControlInit(CONTROL_mppt); break;
        case 'n': ControlInit(CONTROL_mppt2); break;
        }
      }
      OUT2N("oData.iControl",oData.iControl) 
      SettingSave(); 
      return;
    default: OUT2N("no case for",c) return;
    }
    OUT2N("wButtons",wButtons)
  }
  else if (iNow < iTimeRead)  return;

  if (!digitalRead(pin_Left)) wButtons |= _ButtonDown;
  if (!digitalRead(pin_Right)) wButtons |= _ButtonUp;
  if (!digitalRead(pin_Push)) wButtons |= _ButtonPush;
  //OUT2N("wButtons",wButtons);

  if (g_sMess != "")
  {
    if (wButtons)
    {
      g_sMess = "";
      iTimeRead = iNow + 1000;
    }
    return;
  }
  
  if (wButtons & _ButtonPush)
  {
    iModeAdd++;
    if (iModeAdd > ADD_Wifi) iModeAdd = ADD_Control;
    iTimeAdd = iNow + 5000;
    iTimeRead = iNow + 500;
    iModeDisplay = DISPLAY_NUMBERS;
    return;
  }
  else if (iNow > iTimeAdd)
  {
    if (iModeAdd > 0)
    {
      OUT2N("EEPROM saved. fUin",oData.fUin)
      SettingSave();
    }
    iModeAdd = 0;
    if (wButtons & _ButtonUp)
    {
      if (iModeDisplay < DISPLAY_LOG_4) iModeDisplay++;
      iTimeRead = iNow + 500;
    }
    if (wButtons & _ButtonDown)
    {
      if (iModeDisplay > DISPLAY_NUMBERS) iModeDisplay--;
      iTimeRead = iNow + 500;
    }
    return;
  }
  
  int iAdd = 0;
  if (wButtons & _ButtonDown)
  {
     OUT("\tdown")
    iAdd = -1;
  }
  if (wButtons & _ButtonUp)
  {
     OUT("\tup")
     iAdd = +1;
  }

  if (iAdd!=0)
  {
    switch (iModeAdd)
    {
    case ADD_Control:
      oData.iControl += iAdd;
      CLAMP(oData.iControl,CONTROL_NONE,CONTROL_mppt2)
      ControlInit(oData.iControl);
      break;
    case ADD_Uin:
      oData.fUin += (float)iAdd/10.0;
      if (oData.fUin > MAX_V)  oData.fUin = MAX_V;
      if (oData.fUin < MIN_V)  oData.fUin = MIN_V;
      OUT2N(" change fUin to ",oData.fUin)
      break;
    case ADD_Uout:
      oData.fUout += (float)iAdd/10.0;
      if (oData.fUout > MAX_V)  oData.fUout = MAX_V;
      if (oData.fUout < MIN_V)  oData.fUout = MIN_V;
      OUT2N(" change fUout to ",oData.fUout)
      break;
    case ADD_Wifi:
     //oData.wSetting ^= 1UL << 1;
     //oData.wSetting ^= SETTING_WIFI;
     oData.wSetting = 0;
     if (iAdd>0)
     {
       oData.wSetting |= SETTING_WIFI;
      if (bWifiServer = SetupWifi())  display.println("no Wifi !");
     }
     else
     {
       oData.wSetting &= ~SETTING_WIFI;
       //WiFi.mode(WIFI_OFF);
     }
      OUT2N(" new wSetting",oData.wSetting)
      break;
    }
    iTimeAdd = iNow + 5000;
    iTimeDisplay = 0;
    iTimeRead = iNow + 250;
  }
}


void Display()
{
  if (iNow < iTimeDisplay)  return;
  iTimeDisplay = iNow + TIME_Display;

  
  display.clear();
  display.setColor(WHITE);

  display.setFont(ArialMT_Plain_16); // Dialog_plain_32 ArialMT_Plain_10
  display.setTextAlignment(TEXT_ALIGN_RIGHT);
  PrintFloat(40,0,oAdc.fUin,1,"V");
  PrintFloat(82,0,oAdc.fIout,1,"A");
  PrintFloat(128,0,oAdc.fUout,1,"V");

  if (g_sMess != "")
  {
    display.setFont(ArialMT_Plain_10); // Dialog_plain_32 ArialMT_Plain_10
    display.setTextAlignment(TEXT_ALIGN_LEFT);
    display.drawStringMaxWidth(0, 16, 128,g_sMess);
    display.display();
    return;
  }
  
  display.setFont(ArialMT_Plain_10); // Dialog_plain_32 ArialMT_Plain_10
  display.setTextAlignment(TEXT_ALIGN_LEFT);
  if (oData.iControl)
  {
    display.drawString(64, 35,String(oDac.iIn) );
    display.drawString(64, 45,String(oDac.iOut) );
  }
  display.setTextAlignment(TEXT_ALIGN_RIGHT);
  
  switch (iModeDisplay)
  {
  case DISPLAY_NUMBERS:
    display.setFont(ArialMT_Plain_24); // Dialog_plain_32 ArialMT_Plain_10
    display.drawString(64, 40,String(iNow%3000<1000 ? oAdc.fUin : oAdc.fUout) );
    display.drawString(128, 40,String(oAdc.fIout) );
    switch (iModeAdd)
    {
    case ADD_Control:
    {
      //display.drawLine(0,39,60,39);
      display.drawString(60, 16,"mode" );
      String s;
      switch(oData.iControl)
      {
        case CONTROL_NONE: s = "none";  break;
        case CONTROL_Uout: s = "U_out";  break;
        case CONTROL_Uin: s = "U_in";  break;
        case CONTROL_mppt: s = "mppt";  break;
        case CONTROL_mppt2: s = "mppt2";  break;
      }
      display.drawString(128, 16,s );
    }
      break;
    case ADD_Uin:
      //display.drawLine(0,39,60,39);
      display.drawString(60, 16,"U_in" );
      display.drawString(128, 16,String(oData.fUin) );
      break;
    case ADD_Uout:
      //display.drawLine(0,39,60,39);
      display.drawString(60, 16,"U_out" );
      display.drawString(128, 16,String(oData.fUout) );
      break;
    case ADD_Wifi:
      display.drawString(60, 16,"wifi" );
      display.drawString(128, 16, oData.wSetting&SETTING_WIFI == SETTING_WIFI ? "yes" : "no" );
      break;
     default:
      display.drawString(60, 16,String(oData.fUin) );
      display.drawString(128, 16,String(oData.fUout) );
    }
    break;
  case DISPLAY_LOG_1:
  case DISPLAY_LOG_2:
  case DISPLAY_LOG_3:
  case DISPLAY_LOG_4:

    #define GRAPHS 4

    int x0;
    int aY0[GRAPHS];
    float fUmax = oAdcLogMax.fUout > oAdcLogMax.fUin ? oAdcLogMax.fUout : oAdcLogMax.fUin;
    display.setTextAlignment(TEXT_ALIGN_LEFT);
    PrintFloat(0,16,fUmax,0,"V");
    display.setTextAlignment(TEXT_ALIGN_RIGHT);
    PrintFloat(128,16,oAdcLogMax.fIout,0,"A");
    display.setTextAlignment(TEXT_ALIGN_CENTER);
    PrintFloat(64,16,fUmax*oAdcLogMax.fIout,0,"W");
    
    for (int i=0; i<ADC_LOG; i++)
    {
      adc_float_t o = aoAdcLog[(iAdcLog+i)%ADC_LOG];

      int x = 128-i;  // 128-
      int aY[GRAPHS];
      aY[0] = 64 - 48 * o.fUout / fUmax;
      aY[1] = 64 - 48 * o.fUin / fUmax;
      aY[2] = 64 - 48 * o.fIout / oAdcLogMax.fIout;
      aY[3] = 64 - 48 * (o.fUout*o.fIout) / (fUmax*oAdcLogMax.fIout);

      if (i)
      {
        for (int j=0; j<GRAPHS; j++)
        {
          display.drawLine(x0,aY0[j],x,aY[j]);
        }
      }
      x0 = x;
     for (int j=0; j<GRAPHS; j++)  aY0[j] = aY[j];
    }
    
  }
  display.display();
}


void ControlInit(byte iControlNew)
{
  oData.iControl = iControlNew;
  OUT2N(" change iControl to ",oData.iControl)
  switch(oData.iControl)
  {
    case CONTROL_NONE: break;
    case CONTROL_Uout: break;
    case CONTROL_Uin: break;
    case CONTROL_mppt: oDac.iIn = oMpp.iDacPMax;  break;
    case CONTROL_mppt2: oDac.iIn = oMpp.iDacPMax;  break;
  }
}

boolean _MpptCheckOut(unsigned long iMillisNext)
{
  //_DacOutDisable();
  _DacOutWrite(oDac.iOut);
  
  if (oAdcLatest.fUout > oData.fUout)
  {
    oMpp.bOvervoltage = true;
    oMpp.iScanPos = -1; // abort a possible running scan
    oMpp.fPLastProbe = 0; // abort a possibe probe (mppt2)
    
    if (oDac.iOut < DAC_OutMax) oDac.iOut++;
    OUT2T("overvoltage",oAdcLatest.fUout) OUT2T("U_in",oAdcLatest.fUin) OUT2N("dac out",oDac.iOut)
    _DacOutWrite(oDac.iOut);
    return true;
  }

  oDac.iOut -= 10;    // do not limit charging voltage by dac_out without overvoltage 
  CLAMP(oDac.iOut,DAC_OutMin,DAC_OutMax)
  
  if (oMpp.bOvervoltage)
  {
    if (oDac.iOut > DAC_OutMin)
    {
      OUT2T("overvoltage recovery",oAdcLatest.fUout) OUT2T("U_in",oAdcLatest.fUin) OUT2N("dac out",oDac.iOut)
      _DacOutWrite(oDac.iOut);
      return true;
    }
    oMpp.bOvervoltage = false;
    oMpp.iTimeNextScan = iNow + iMillisNext;  // might only be a cloud
  }
  return false;
}

boolean _MpptCheckNextScan()
{   
  if (iNow < oMpp.iTimeNextScan)
    return true;

  // try new mpp scan
  adc_float_t o = aoAdcLog[iAdcLog];
  float fPMin = o.fUout * o.fIout;
  float fPMax = fPMin;
  int iTest = MPPT_WaitStablePV / TIME_ADC;
  for (int i=0; i<iTest; i++)
  {
    adc_float_t o = aoAdcLog[(iAdcLog+i)%ADC_LOG];
    float fP = o.fUout * o.fIout;
    if (fPMin > fP) fPMin = fP;
    else if (fPMax < fP) fPMax = fP;
  }
  if (fPMax - fPMin > (0.1 * oAdcLogMax.fUout *oAdcLogMax.fIout)  ) // only start new mpp scan when power has not changed for more then 10% of max power
  {
    OUT2N("solar power not stable for mpp scan",fPMax - fPMin)
    return true;
  }
  if (fPMax  < (0.03 * oAdcLogMax.fUout *oAdcLogMax.fIout)  ) // no new mpp scan when max power was less then 3% of overall max power
  {
    OUT2N("solar power to small for mpp scan",fPMax)
    return true;
  }
  return false;
}

void Control()
{
    oAdcLatest = aoAdcLog[iAdcLog]; // lated adc
    float fP = oAdcLatest.fUout * oAdcLatest.fIout;

    if (oAdcLatest.fUin < 5.0)
    {
      display.clear();
      display.display();
      esp_sleep_enable_timer_wakeup(5 * uS_TO_S_FACTOR);
      OUT2N("Going to sleep now, U_in",oAdcLatest.fUin)
      delay(1000);
      Serial.flush(); 
      esp_deep_sleep_start();
    }
    
    switch(oData.iControl)
    {
    case CONTROL_NONE:
      _DacOutDisable();
      dacDisable(PIN_DACin);
      break;

    case CONTROL_Uout:
    {
      //if (++oDac.iOut > DAC_OutMax) oDac.iOut = DAC_OutMin;
      if (oDac.iIn < DAC_InMax) oDac.iIn++;    // do not limit input voltage 

      float fUDiff = oAdcLatest.fUout - oData.fUout;
      oDac.iOut += fUDiff / 4 + (fUDiff > 0 ? 1 : -1);
      //oDac.iOut += (oAdcLatest.fUout - oData.fUout) / 2;
      CLAMP(oDac.iOut,DAC_OutMin,DAC_OutMax)

      OUT_Log("CONTROL_Uout")
      dacWrite(PIN_DACin,oDac.iIn);
      _DacOutWrite(oDac.iOut);
      break;
    }  
    case CONTROL_Uin:
    {
      oDac.iOut -= 10;    // do not limit charging voltage by dac_out without overvoltage 
      CLAMP(oDac.iOut,DAC_OutMin,DAC_OutMax)
      float fUDiff = oAdcLatest.fUin - oData.fUin;
      oDac.iIn += fUDiff / 4 + (fUDiff > 0 ? 1 : -1);
      CLAMP(oDac.iIn,DAC_InMin,DAC_InMax)
      dacWrite(PIN_DACin,oDac.iIn);
      _DacOutWrite(oDac.iOut);
      break;
    }  
    case CONTROL_mppt2:
    {
      if (_MpptCheckOut(MPPT_ProbeMillis))
        break;
      if (oMpp.fPLastProbe)
      {
        if (fP > oMpp.fPLastProbe)
        {
          oDac.iIn = oMpp.iDacPMax = oMpp.iScanPos;
        }
        else
        {
          oMpp.iProbeDirection *= -1;
        }
        oMpp.fPLastProbe = 0;
        oMpp.iTimeNextScan = iNow + MPPT_ProbeMillis;
        break;
      }

      if (_MpptCheckNextScan())
        break;

      //OUT_Log(oMpp.iProbeDirection)
      oMpp.iScanPos = oDac.iIn + oMpp.iProbeDirection;
      dacWrite(PIN_DACin,oMpp.iScanPos);
      oMpp.fPLastProbe = fP;
      break;
    }
    case CONTROL_mppt:
    {
      if (_MpptCheckOut(MPPT_ScanSeconds * 1000))
        break;
        
      if (oMpp.iScanPos >= 0)  // doing mpp scan
      {
        OUT2N(oMpp.iScanPos,fP)
        if (oMpp.fPMax < fP) 
        {
          oMpp.fPMax = fP;
          oMpp.iDacPMax = oMpp.iScanPos;
        }
        if (oMpp.iScanPos < oDac.iIn)
        {
          if (oMpp.fPMin > fP) 
          {
            oMpp.fPMin = fP;
            oMpp.iDacPMin = oMpp.iScanPos;
          }
          
        }
        oMpp.iScanPos++;
        if (  (oMpp.iScanPos < DAC_InMax) && (oMpp.iScanPos-oMpp.iDacPMax < 10) )    // if no new mpp found there will be no new anyway
        {
          dacWrite(PIN_DACin,oMpp.iScanPos);
          break;
        }
        
        // scan finished
        oMpp.iScanPos = -1;
        
        OUT2T("max power",oMpp.fPMax) OUT2N("at dac",oMpp.iDacPMax)

        //oDac.iIn = oMpp.iDacPMax;
        oDac.iIn = (50 * oDac.iIn + 50 * oMpp.iDacPMax)/100;  // low pass
        OUT2T("new iIn",oDac.iIn)

        OUT2N(oMpp.fPMax - oMpp.fPMin,0.1 * oMpp.fPMax)
        if (oMpp.fPMax - oMpp.fPMin < 0.1 * oMpp.fPMax) // if power drop to low at begin of scan, do start earlier
        {
          if (oDac.iIn+oMpp.iScanBegin > DAC_InMin ) oMpp.iScanBegin--;
        }
        else
        {
          if (oMpp.iScanBegin < -5) oMpp.iScanBegin++;
        }
        OUT2T("min left power",oMpp.fPMin) OUT2N("iScanBegin",oMpp.iScanBegin)
        
        dacWrite(PIN_DACin,oDac.iIn);
        oMpp.iTimeNextScan = iNow + MPPT_ScanSeconds * 1000;
        break;
      }

      dacWrite(PIN_DACin,oDac.iIn);

      if (_MpptCheckNextScan())
        break;
        
      oMpp.iScanPos = oDac.iIn + oMpp.iScanBegin;
      if (oMpp.iScanPos < DAC_InMin) oMpp.iScanPos = DAC_InMin;

      OUT2T(oMpp.iScanPos,DAC_InMax) 
      OUT_Log("new mpp scan")
      
      oMpp.fPMax = 0;
      oMpp.fPMin = 9999;
      
      dacWrite(PIN_DACin,oMpp.iScanPos);
      break;
    }
            
    }
}

boolean ReadAnalog()
{
  oAdcSum.iUin += analogRead(PIN_Uin);
  oAdcSum.iUout += analogRead(PIN_Uout);
  oAdcSum.iIout += analogRead(PIN_Iout);
  iAdcSum++;

  if (iNow < iTimeAdc)
    return false;
  iTimeAdc = iNow + TIME_ADC;

  oAdc.fUin = (float)oAdcSum.iUin / iAdcSum;
  oAdc.fUout = (float)oAdcSum.iUout / iAdcSum;
  oAdc.fIout = (float)oAdcSum.iIout / iAdcSum;

  //OUT2T(analogRead(PIN_Uin),analogRead(PIN_Uout))
  oAdc.fUin    = mapf(oAdc.fUin,   0.0, 5957.0 ,  0.0, 40.00 ,false);
  oAdc.fUout    = mapf(oAdc.fUout, 0.0, 3964.5 ,  0.0, 26.92 ,false);
  if (oAdc.fIout > oAdcSum.fOffsetI)
    oAdc.fIout -= oAdcSum.fOffsetI;
  else
  {
    oAdcSum.fOffsetI = oAdc.fIout;
    oAdc.fIout = 0;
    OUT2N("new fOffsetI",oAdcSum.fOffsetI)
  }
  
  //OUT2T("-",oAdc.fIout)
  oAdc.fIout    = mapf(oAdc.fIout,    0.0,1720.0,  0.0,4.0,false);

  //OUT2T("iUin",oAdcSum.iUin/iAdcSum)OUT2T("=",oAdc.fUin) OUT2T("iUout",oAdcSum.iUout/iAdcSum) OUT2T("=",oAdc.fUout) OUT2T("fIout",oAdc.fIout) OUT2T("=",oAdc.fIout) OUTN(iAdcSum);
  
  iAdcSum = oAdcSum.iUin = oAdcSum.iUout = oAdcSum.iIout = 0;

  iAdcLog = (iAdcLog +ADC_LOG - 1) % ADC_LOG;
  memcpy(&aoAdcLog[iAdcLog],&oAdc,sizeof(oAdc));

  if (oAdcLogMax.fUin < oAdc.fUin)  oAdcLogMax.fUin = 1 + (int)oAdc.fUin;
  if (oAdcLogMax.fUout < oAdc.fUout)  oAdcLogMax.fUout = 1 + (int)oAdc.fUout;
  if (oAdcLogMax.fIout < oAdc.fIout)  oAdcLogMax.fIout = 1 + (int)oAdc.fIout;
  return true;
}

unsigned long iTimeBlink = 0;
boolean bBlink = false;

// the loop function runs over and over again forever
void loop() 
{
  iNow = millis();

  //digitalWrite(LED_BUILTIN, iNow%1000 < 200);
  digitalWrite(LED_BUILTIN, bBlink);
  if (iNow > iTimeBlink)
  {
    iTimeBlink = iNow + 4*oDac.iIn-DAC_OutMin+50;
    bBlink = !bBlink;
  }

 
  ReadInput();

  if (ReadAnalog())
  {
    Control();
  }
    
  Display();
  
}

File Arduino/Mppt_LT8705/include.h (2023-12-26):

//#include <driver/dac.h>

#include <EEPROM.h>
#include "net.h"

#define uS_TO_S_FACTOR 1000000  

unsigned long iNow = 0;

unsigned long iTimeDisplay = 0;
#define TIME_Display 200
unsigned long iTimeRead = 0;
#define TIME_ADC 50
unsigned long iTimeAdd = 0;


#define MAX_V 80.0
#define MIN_V 1.0

#define CONTROL_COUNT 5
#define CONTROL_NONE 0
#define CONTROL_Uout 1
#define CONTROL_Uin 2
#define CONTROL_mppt 3
#define CONTROL_mppt2 4


#define ADD_Control 1
#define ADD_Uin 2
#define ADD_Uout 3
#define ADD_Wifi 4
int iModeAdd = 0;

int iLogZoom = 1;

#define DISPLAY_NUMBERS 0
#define DISPLAY_LOG_1 1
#define DISPLAY_LOG_2 2
#define DISPLAY_LOG_3 3
#define DISPLAY_LOG_4 4

int iModeDisplay = DISPLAY_LOG_1; //DISPLAY_NUMBERS;

#define SETTING_WIFI 1  // wifi on or off

#define EEPROM_VERSION 1
typedef struct {
    uint32_t iVersion = EEPROM_VERSION;
    uint16_t  wSetting = 0; 
    char sSSID[31] = "";
    char sPwd[31] = "";
    char sApiKey[20] = "";
    float fUin = 30.0;
    float fUout = 29.4;
    uint8_t iControl = 0;
  } Data;
Data oData;

void SettingSave()
{
  EEPROM.put(0,oData);
  EEPROM.commit(); 
}

bool bWifiServer = false;


#include "SSD1306Wire.h" // legacy include: `#include "SSD1306.h"`
// custom fonts: http://oleddisplay.squix.ch
#include "Dialog_plain_32.h"

// Initialize the OLED display using Wire library
SSD1306Wire  display(0x3c, 13, 14); // I2C_Scanner: 0x3C

#define pin_Right 9
#define pin_Push 11
#define pin_Left 12

#define _ButtonDown 1
#define _ButtonUp 2
#define _ButtonPush 4

byte wButtons;

#define PIN_Uin 5
#define PIN_Uout 3
#define PIN_Iout 2


#define DAC_InMin 0
#define DAC_InMax 255
#define DAC_OutMin 0
#define DAC_OutMax 255

#define PIN_DACin 17
#define PIN_DACout 18
#define CHANNEL_DacOut 0

void _DacOutWrite(byte iOut)
{
  ledcWrite(CHANNEL_DacOut, iOut);
  //pinMode(PIN_DACout,OUTPUT);
}
void _DacOutDisable()
{
  pinMode(PIN_DACout,INPUT);
}

typedef struct
{
  boolean bIn = false;
  int iIn = 95;
  boolean bOut = true;
  int iOut = 95;
} dac_t;
dac_t oDac;

unsigned long iTimeAdc = 0;


typedef struct
{
  unsigned int iUin;
  unsigned int iUout;
  unsigned int iIout;
  float fOffsetI = 125;
} adc_analog_t;

adc_analog_t oAdcSum;
int iAdcSum = 0;

typedef struct
{
  float fUin;
  float fUout;
  float fIout;
  
} adc_float_t;

adc_float_t oAdc;
adc_float_t oAdcLatest;

#define ADC_LOG 128
adc_float_t aoAdcLog[ADC_LOG];
int iAdcLog = 0;
adc_float_t oAdcLogMax;



#define MPPT_ScanOffset 64
#define MPPT_ScanSize 128
#define MPPT_ScanSeconds 5 // 
#define MPPT_ProbeMillis 500
#define MPPT_WaitStablePV 1000 // millisesonds to have a stable pv input after iTimeNextScan that a next scan is initiated
typedef struct
{
  // byte iPosDo = 95;   // 95 = 1.2V = no influence on hardware ..
  int iScanWindow = MPPT_ScanSize;
  int iScanBegin = -10;
  int iScanPos = -1;  // no scan 
  float fPMax = 0;
  int iDacPMax = 0;
  float fPMin = 0;
  int iDacPMin = 0;
  boolean bOvervoltage = false;
  unsigned long iTimeNextScan = 0;
  float fPLastProbe = 0;
  int iProbeDirection = 1;
  
} mppt_t;

mppt_t oMpp;

String g_sMess = "";


#define CLAMP(v,vMin,vMax)  if (v > vMax)  v = vMax;  if (v < vMin)  v = vMin;

double mapf(double val, double in_min, double in_max, double out_min, double out_max, boolean bClamp=false) 
{
  double f = (val - in_min) * (out_max - out_min) / (in_max - in_min) + out_min;
  if (bClamp)
  {
    if (f > out_max)  f = out_max;
    else if (f < out_min) f = out_min;
  }
  return f;
}

#ifdef SERIALDEBUG
  #define DEBUG(code) {code}
  #define OUT(s)  {SERIALDEBUG.print(s);}
  #define OUT2(s,i) {SERIALDEBUG.print(s);SERIALDEBUG.print(": ");SERIALDEBUG.print(i);}
  #define OUT2T(s,i)  {SERIALDEBUG.print(s);SERIALDEBUG.print(": ");SERIALDEBUG.print(i);SERIALDEBUG.print("  ");}
  #define OUT2N(s,i)  {SERIALDEBUG.print(s);SERIALDEBUG.print(": ");SERIALDEBUG.print(i);SERIALDEBUG.println();}
  #define OUTN(s) {SERIALDEBUG.println(s);}
  #define OUTI4(i){if (i<10) SERIALDEBUG.print("   ");  else if (i<100) SERIALDEBUG.print("  ");  else if (i<1000)  SERIALDEBUG.print(" "); SERIALDEBUG.print(i);}
#else
  #define DEBUG(code)
  #define OUT(s)
  #define OUT2(s,i)
  #define OUT2T(s,i)
  #define OUT2N(s,i)
  #define OUTN(s)
  #define OUTI4(i)
#endif

#define OUT_Log(s) {  OUT(s) OUT2T("\tP",oAdcLatest.fUout * oAdcLatest.fIout) OUT2T("fUout",oData.fUout) OUT2T("U_in",oAdcLatest.fUin) OUT2T("U_out",oAdcLatest.fUout) OUT2T("dac in",oDac.iIn) OUT2N("dac out",oDac.iOut)  }

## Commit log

2024-01-23 footsprints verified and sd card added
    [Esp20A80V.blend, Esp20A80V.kicad_pcb, Esp20A80V.kicad_sch]
2024-01-23 better circuit
    [Esp20A80V.kicad_pcb]
2024-01-23 jst ph2.0 instead of dupont female
    [Esp20A80V.kicad_pcb, Esp20A80V.kicad_sch]
